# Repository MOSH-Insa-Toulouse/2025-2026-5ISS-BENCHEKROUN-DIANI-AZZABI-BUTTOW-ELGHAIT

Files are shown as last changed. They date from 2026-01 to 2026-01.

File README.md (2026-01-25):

# Gas Sensor - IoT Project

This project presents the complete development of an IoT gas sensor system, encompassing the entire pipeline from chemical synthesis to cloud integration. The work includes:

- **Chemical production** of WO₃ (tungsten trioxide) nanoparticle-based gas sensors in the laboratory
- **Electrical characterization** and datasheet development
- **LoRaWAN communication** testing with Arduino microcontroller
- **Node-RED integration** for real-time data visualization and monitoring
- **PCB system design** for the complete electronic circuit
- **Mobile application** development for user interaction

This multidisciplinary approach demonstrates a complete IoT solution from sensor fabrication to end-user interface.

## MOx Sensor Manufacturing

During a week at the AIME laboratory of INSA Toulouse, we fabricated our own MOx (Metal Oxide) gas sensor. This chapter describes how the MOx gas sensor was fabricated, from the micro-structure on the chip to the final packaged component ready for tests. The main goal is to build a sensor with interdigitated electrodes and a metal-oxide active layer (WO₃), and to make sure it can be electrically connected and handled safely during measurements.

### 1.1 MOx Sensor Architecture

The sensor is based on a small chip that includes a heating element (to control the operating temperature) and metal electrodes where the metal-oxide material will be deposited. The device is designed so that the gas-sensitive layer can change its resistance depending on the surrounding atmosphere.

### 1.2 Photolithography

First, the polysilicon heating element (used to heat the MOx resistor, lower its resistance, and remove water residues) was already manufactured in the AIME clean room by professionals. It was obtained by depositing a polysilicon layer and then patterning it using a photoresist mask activated by UV light.

Then, metallization was performed by depositing a thin aluminum layer (about 500 nm) to create electrodes and electrical contacts. After that, metal etching defined the final electrode patterns by removing unwanted aluminum. This step used a resist coating, UV exposure with a mask, development, annealing cycles, and a chemical etching bath, with microscope inspections to verify quality after each stage.

### 1.3 Metal Oxide (MOx) Synthesis

The active sensing material is tungsten trioxide (WO₃). The synthesis process consists of two steps: first, seed preparation (chemical mixing and centrifugation to collect the precipitate), and second, nanowire growth using a hydrothermal process at high temperature, followed by rinsing and storage. This method aims to produce homogeneous nanostructures suitable for gas sensing.

To place the WO₃ nanoparticles onto the interdigitated electrodes, dielectrophoresis is used: a small drop of nanoparticle solution is deposited on the chip, and an AC voltage is applied to align the particles between the electrodes. After rinsing and drying, the chip is checked under an optical microscope to confirm a uniform and well-aligned active layer.

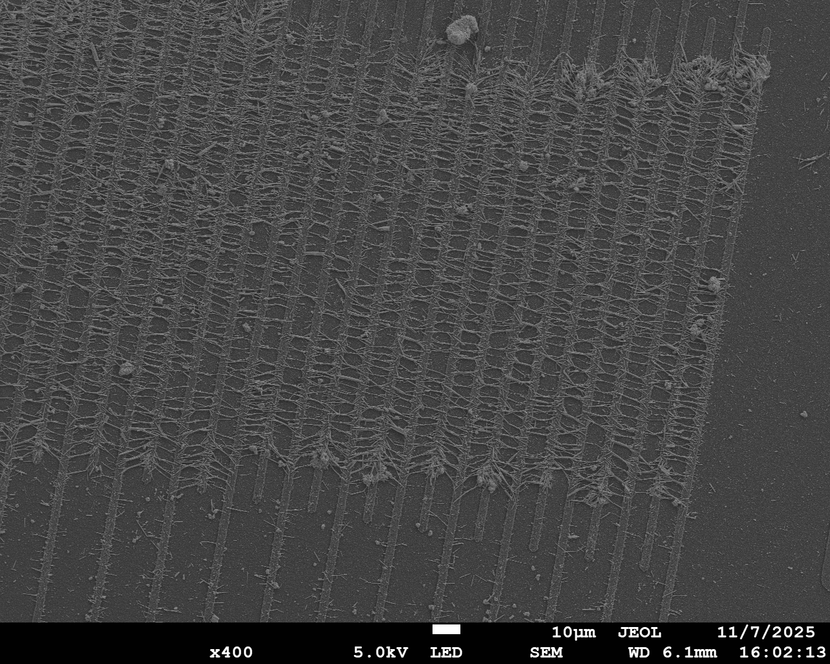
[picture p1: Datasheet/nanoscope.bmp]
Nanoscope view of the sensor


### 1.4 Packaging

Finally, the sensor is packaged using a JEDEC TO-5 metal can package with 10 pins. The chip is placed on a glass support to provide electrical isolation, and wire bonding is used to connect the chip pads to the package pins. This creates a robust component that can be connected to external electronics for characterization and integration.

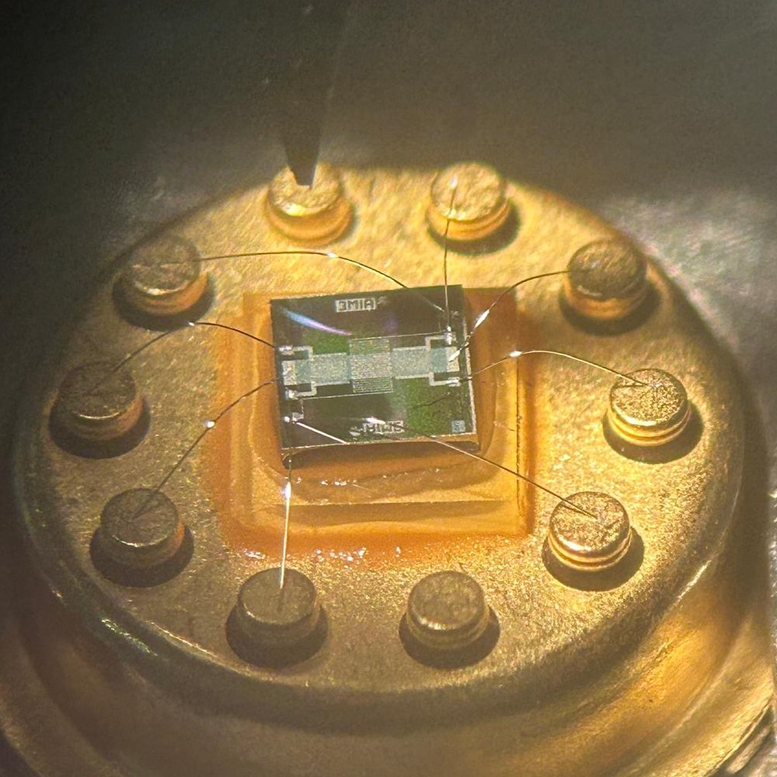
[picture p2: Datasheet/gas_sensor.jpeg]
Packaged gas sensor


## Sensor Characterization

After fabricating the sensor, we characterized two key parts of the device: the integrated thermistor (used to estimate temperature) and the MOx gas-sensing resistance (WO₃). The goal is to obtain practical electrical values that can later be used for conditioning, calibration, and integration into electronics.

### 2.1 Thermistor

The thermistor (called R_alu) is treated as a PTC component, meaning its resistance increases with temperature. Since it was not fully characterized, we assumed an approximate coefficient of 1 Ω per °C, based on a similarity with a Pt100-like behavior. A proper method would be to heat it while comparing with a reference thermometer, but this was not done, and the approximation was considered "good enough" for operating the MOx sensor.

To find the room-temperature reference resistance, we measured an I-V curve using a waveform generator and an instrumentation setup, then applied Ohm's law. The nominal resistance obtained was about 86 Ω at ambient temperature (around 21°C). We also observed non-linearity at higher voltage, likely caused by self-heating of the thermistor.

### 2.2 MOx Resistance

**Nominal resistance:** The WO₃ sensing layer has a very high resistance in its reduced form, in the GΩ range, which makes measurement difficult due to the need for a precise current source and because thermal noise becomes significant. As a result, the reported value is a rough estimate, but we obtained a typical resistance around 16 GΩ.

**Sensitivity to ethanol:** We performed an experiment to evaluate the sensor response to ethanol vapor. First, the sensor temperature is increased (around 550 K) to evaporate moisture and reduce resistance. Then the test is performed in two phases: a regeneration phase under dry air (to "regenerate" the sensor surface), followed by a detection phase under an ethanol/air mixture (about 1000 ppm). During exposure, the resistance drops with an exponential-like behavior.

From this test, we extracted several performance indicators, including:
- **Relative resistance change:** approximately 64% for our test conditions
- **Sensitivity coefficient:** based on (R_air - R_eth)/R_air
- **Response time:** about 88 seconds to reach 10% of the final value
- **Sensitivity:** 85,000 Ω/ppm
- **Detection limit:** approximately 38.3 ppm, based on the Arduino ADC resolution (10-bit), amplifier gain, and the measured sensitivity

## Integration into a Smart Device

This chapter focuses on how we integrated the MOx gas sensor into a smart embedded device using an Arduino as the main controller. The objective was to build a system able to read the sensor through an adapted analog front-end, and to prepare the hardware for a future connected version.

### 3.1 Arduino-based Prototype (Hardware Concept)

Because the final PCB/shield could not be manufactured in time, we used a prototype setup where an Arduino would interface with the gas sensor through signal conditioning. We temporarily relied on a commercial Grove gas sensor to keep the integration moving while the custom MOx board was still under development.

The system was implemented using Arduino Uno with the following sensors:
- **Temperature and humidity sensor** - for environmental monitoring
- **Grove gas sensor** - commercial reference sensor
- **Our MOx gas sensor** - sensor fabricated with WO₃ nanoparticles

### 3.2 Signal Conditioning for the MOx Sensor

Since the WO₃ sensing element can reach very high resistance (GΩ range), the sensor cannot be connected directly to the Arduino ADC. For this reason, we designed a dedicated conditioning stage (based on a transimpedance/very high gain approach) that converts the sensor behavior into a measurable voltage range for the Arduino. We validated this front-end using LTSpice simulations, and we highlight the main challenge: at such high impedance, noise becomes significant, which can limit measurement quality.

### 3.3 Filters and Noise Considerations

To improve stability, we included RC filtering at different points (input/output/feedback and power supply). The theoretical and simulated cut-off frequencies were designed to reduce low-frequency drift and attenuate noise sources such as mains-related interference (50 Hz) and EMC disturbances.

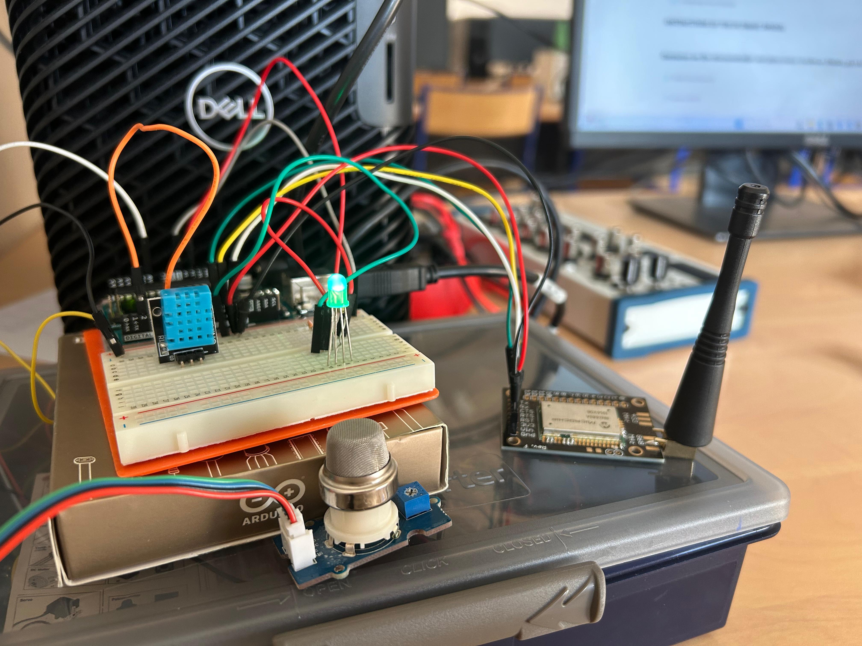
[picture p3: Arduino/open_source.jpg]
Arduino prototype with sensors


### 3.4 Arduino Code Implementation

The Arduino code (`OpenSource_V2.4.ino`) performs:
- Gas sensor reading on pin A0
- LoRaWAN communication through The Things Network (TTN)
- OLED display for local data visualization
- LED alert system when gas values exceed the threshold

**Main code features:**
- Analog reading of the gas sensor (A0)
- Alert threshold: GAZ_VALUE > 100
- Data transmission via LoRaWAN every 10 seconds
- OLED display for visual feedback
- LED alert for gas detection

## Node-RED

The Node-RED system was implemented to receive and process sensor data through the MQTT protocol, connecting to ChirpStack/The Things Network. This provides a visual programming interface for data flow management and real-time monitoring of the gas sensor system.

### 4.1 System Architecture

The Node-RED implementation creates a complete IoT data pipeline that:
- Subscribes to MQTT topics from the LoRaWAN network server (ChirpStack/TTN)
- Processes incoming sensor data in real-time
- Provides visual dashboards for monitoring
- Implements alert logic based on sensor thresholds
- Stores historical data for analysis

### 4.2 MQTT Integration

The system uses an MQTT input node configured to subscribe to the application-specific topic:
- **Topic pattern**: `application/[app-id]/device/+/event/up`
- **QoS Level**: 2 (exactly once delivery)
- **Protocol**: MQTT over ChirpStack/The Things Network

This ensures reliable reception of all uplink messages from the deployed gas sensors in the field.

### 4.3 Data Processing Flow

The implemented flow performs several processing stages:

1. **Message Filtering**: Filters only uplink events (`/event/up`) to ignore other event types
2. **Base64 Decoding**: Extracts and decodes the base64-encoded payload from the LoRaWAN message
3. **Payload Parsing**: Interprets the binary data structure:
   - Byte 0: Sensor ID (identifies which sensor sent the data)
   - Bytes 1-2: 16-bit big-endian integer containing the raw sensor value
   - Conversion: Divides raw value by 100 to obtain the actual measurement
4. **Alert Logic**: Implements threshold-based alerting:
   - Normal operation: value ≤ 80
   - Alert state: value > 80 (triggers "Help" notification)
5. **Data Distribution**: Routes processed data to multiple outputs (debug console, dashboard widgets, data storage)

### 4.4 Node-RED Flow

The visual flow includes:
- MQTT subscriber node for data ingestion
- Function nodes for data transformation and business logic
- Debug nodes for development and troubleshooting
- Dashboard UI nodes for real-time visualization
- Chart nodes for historical trend display

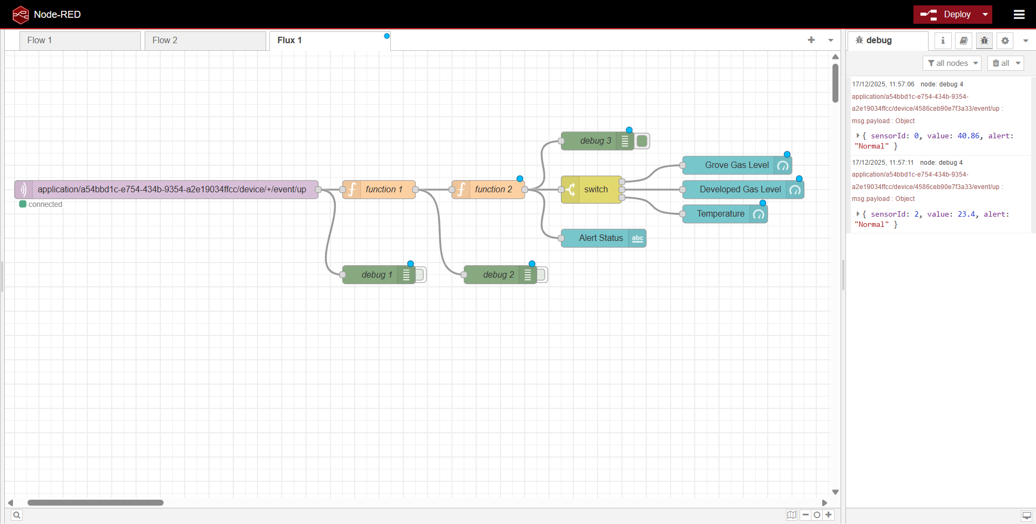
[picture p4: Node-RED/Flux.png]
Node-RED Flow


### 4.5 Dashboard

The Node-RED dashboard provides a web-based interface for real-time monitoring with:

**Display Elements:**
- **Current sensor value**: Real-time display of gas concentration readings
- **Alert status**: Visual indicator showing "Normal" or "Help" states
- **Historical chart**: Time-series graph showing sensor readings over time
- **Sensor identification**: Displays which sensor (by ID) is reporting

**Features:**
- Responsive web interface accessible from any device
- Automatic updates as new data arrives
- Color-coded alerts for quick status assessment
- Historical data visualization for trend analysis

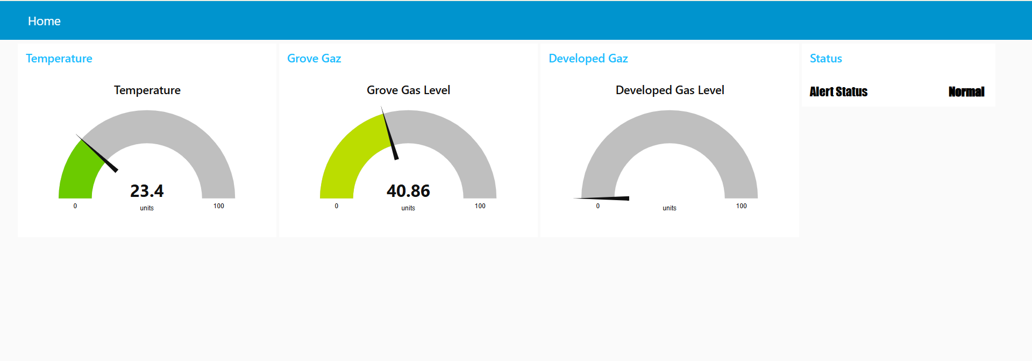
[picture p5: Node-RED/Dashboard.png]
Node-RED Dashboard


### 4.6 Implementation Details

The complete flow configuration is available in the `flows.json` file, which can be imported directly into Node-RED for deployment. The implementation uses standard Node-RED nodes along with the dashboard palette for UI components, making it easy to customize and extend for additional features or sensors.

## The electrical circuit
Here is the complete electrical diagram of our system. It consists of a gas-type switch, a variable resistor using an MCP41100 digital potentiometer, another variable resistor using an MCP41100 digital potentiometer, an Arduino Uno, a gas sensor, and a LoRa module.

Capture d’écran 2026-01-21 à 14 50 42

The fabricated gas sensor exhibits a very high resistance that varies depending on the type and presence of gas. Its resistance is on the order of gigohms, resulting in an extremely low current of the order of nanoamperes flowing into the ADC. Since an Arduino uses a 10-bit ADC, the sensor output signal must be amplified. To address this, we designed an amplification circuit based on an operational amplifier and validated it through LTSpice simulations.
Below is the LTSpice circuit:

Capture d’écran 2026-01-21 à 14 50 59

The circuit includes three filters with different cutoff frequencies to reduce noise and shape the signal:
- A low-frequency filter to suppress sensor noise,
- A notch filter to attenuate 50 Hz power-line interference,
- An anti-aliasing filter to prevent distortion during ADC sampling.

Transient simulations confirmed correct amplifier operation, with a gain of 101, matching theoretical calculations. Frequency analysis using Bode diagrams showed an overall gain of 140 dB, consistent with the expected transfer function. FFT analysis further demonstrated effective noise reduction, particularly at 50 Hz, while highlighting the trade-off between noise suppression and signal distortion when filter capacitance is increased excessively.
Overall, the simulations validate the amplifier design and confirm its suitability for accurately measuring low-current gas sensor signals using low-cost data acquisition systems.

## PCB Design
To bring all the components of our sensor system together, we designed a dedicated Printed Circuit Board (PCB). This board combines all stages of the system into a unified and compact design, providing an optimized layout, enhanced reliability, and efficient operation. The detailed PCB design is shown in the figure below.

Capture d’écran 2026-01-25 à 10 23 23

Below, there is a 3D view of the PCB after conception.

- Front view:

Capture d’écran 2026-01-25 à 10 24 11

- Back view:

Capture d’écran 2026-01-21 à 14 51 32

## MIT App Inventor

The MIT App Inventor application is designed to interface with the Arduino, allowing users to control the system and monitor sensor data in real time.

  Capture d’écran 2026-01-21 à 14 52 11

This MIT App Inventor application functions as a Bluetooth remote control for an Arduino system. It allows the user to first connect to a Bluetooth module (such as HC-05) through a list of available devices, and then send commands either by pressing buttons or using voice commands. The "LED ON" button sends the number 1 to turn on the LED, the "LED OFF" button sends 2 to turn it off, and if the voice recognition detects the word "blink," the app sends 3 to make the LED blink. At the same time, the application can receive and display messages sent by the Arduino via Bluetooth.

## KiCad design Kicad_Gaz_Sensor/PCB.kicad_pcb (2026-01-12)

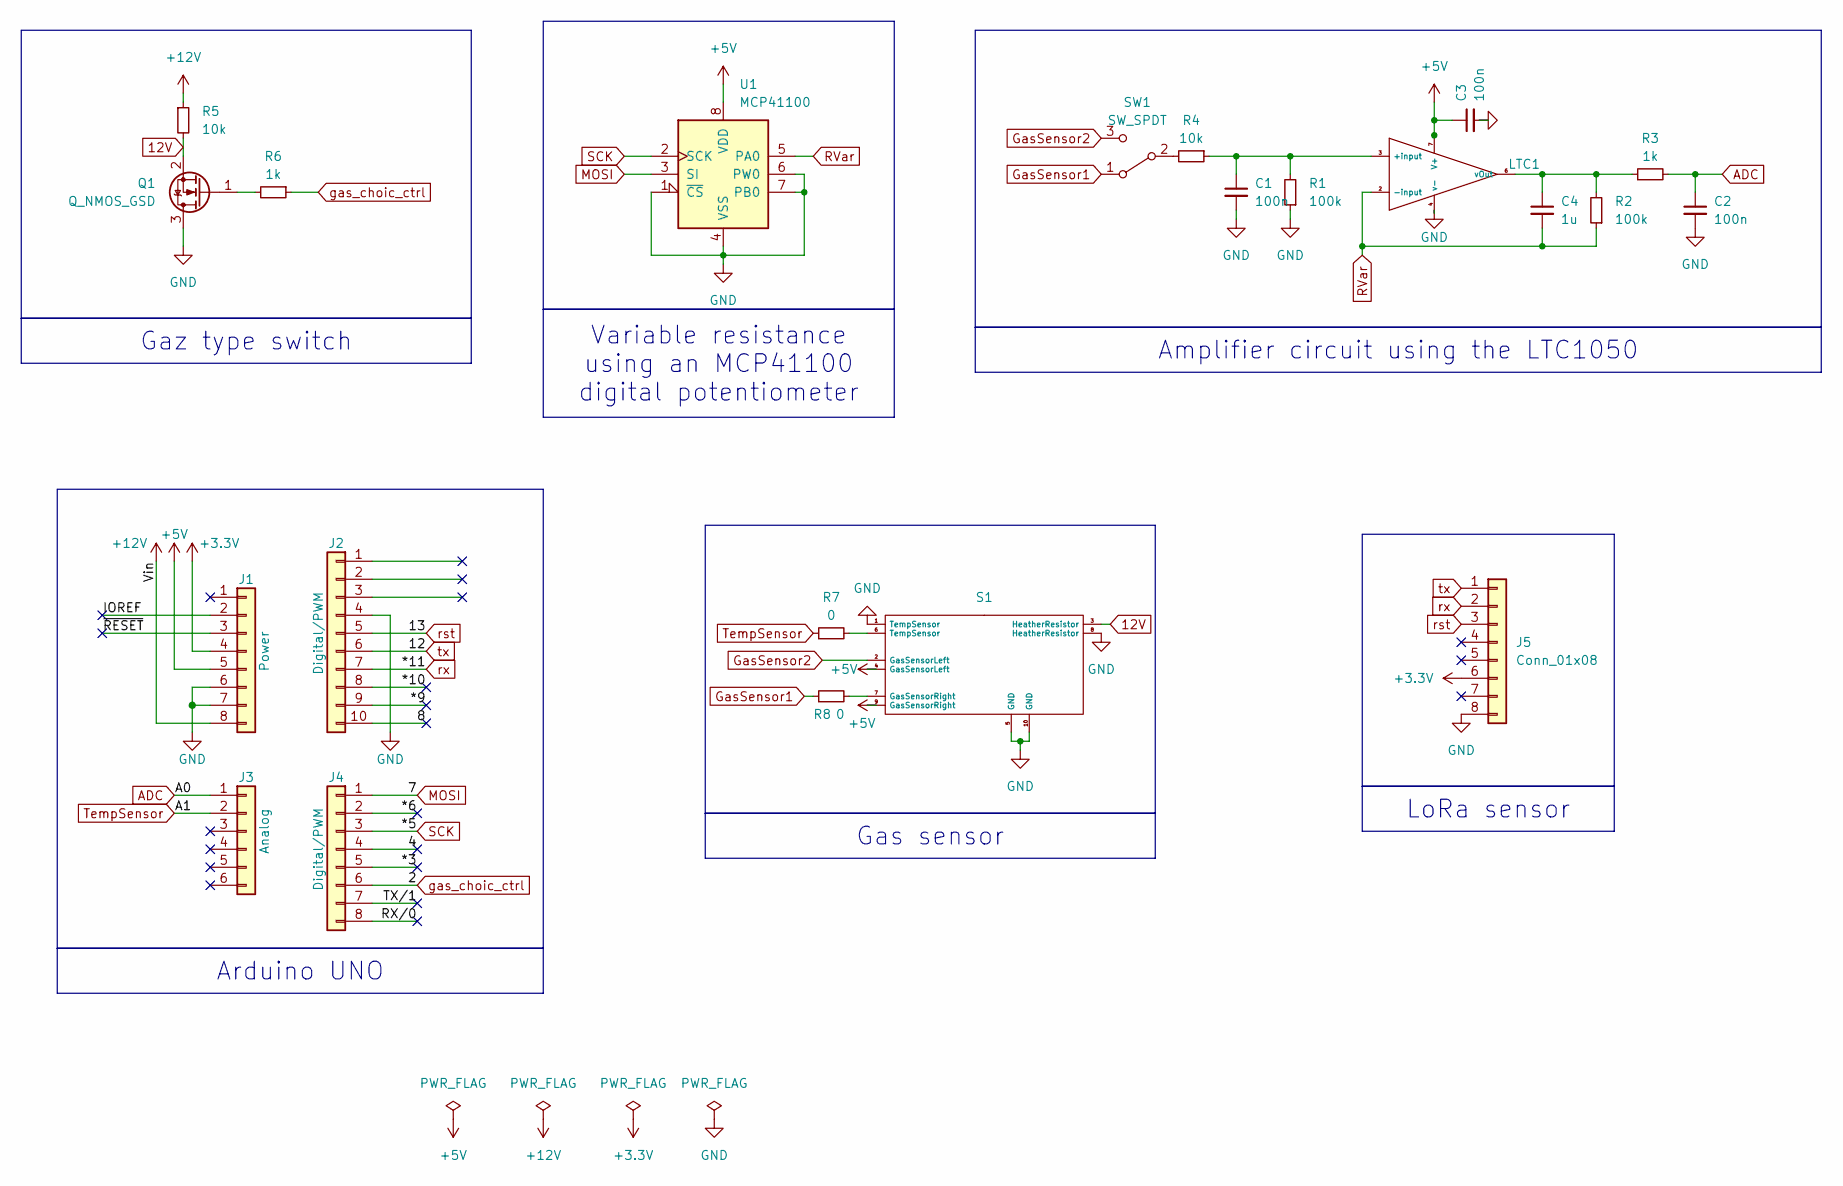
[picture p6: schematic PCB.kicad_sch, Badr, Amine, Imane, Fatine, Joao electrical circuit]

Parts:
C1, C2, C3: 100n; C_Disc_D3.0mm_W1.6mm_P2.50mm
C4: 1u; C_Disc_D3.0mm_W1.6mm_P2.50mm
J1: Power; PinSocket_1x08_P2.54mm_Vertical
J2: Digital/PWM; PinSocket_1x10_P2.54mm_Vertical
J3: Analog; PinSocket_1x06_P2.54mm_Vertical
J4: Digital/PWM; PinSocket_1x08_P2.54mm_Vertical
J5: Conn_01x08; PinSocket_1x08_P2.54mm_Vertical
LTC1: DIP-8_W7.62mm_LongPads
Q1: Q_NMOS_GSD; TO-220-3_Vertical
R1, R2: 100k; R_Axial_DIN0204_L3.6mm_D1.6mm_P5.08mm_Horizontal
R3, R6: 1k; R_Axial_DIN0204_L3.6mm_D1.6mm_P5.08mm_Horizontal
R4, R5: 10k; R_Axial_DIN0204_L3.6mm_D1.6mm_P5.08mm_Horizontal
R7, R8: 0; R_Axial_DIN0204_L3.6mm_D1.6mm_P5.08mm_Horizontal
S1: TO-5-10_Window
SW1: SW_SPDT; SW_Push_2P2T_Toggle_CK_PVA2xxH2xxxxxxV2
U1: MCP41100; DIP-8_W7.62mm

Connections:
12V: Q1.2 (S), R5.2, S1.3 (HeatherResistor)
+3.3V: J1.4, J5.6
+5V: C3.1, J1.5, LTC1.7 (V+), S1.4 (GasSensorLeft), S1.9 (GasSensorRight), U1.8 (VDD)
+12V: J1.8, R5.1
/4: J4.4
/8: J2.10
/*3: J4.5
/*6: J4.2
/*9: J2.9
/*10: J2.8
/IOREF: J1.2
/RX/0: J4.8
/TX/1: J4.7
/~RESET: J1.3
ADC: C2.1, J3.1, R3.2
GND: C1.2, C2.2, C3.2, J1.6, J1.7, J2.4, J5.8, LTC1.4 (v-), Q1.3 (D), R1.1, S1.1 (TempSensor), S1.5 (GND), S1.8 (HeatherResistor), S1.10 (GND), U1.1 (~CS), U1.4 (VSS), U1.6 (PW0), U1.7 (PB0)
GasSensor1: R8.1, SW1.1 (A)
GasSensor2: S1.2 (GasSensorLeft), SW1.3 (C)
MOSI: J4.1, U1.3 (SI)
unnamed: C1.1, LTC1.3 (+input), R1.2, R4.1
unnamed: C4.1, LTC1.6 (vOut), R2.2, R3.1
unnamed: Q1.1 (G), R6.2
unnamed: R7.2, S1.6 (TempSensor)
unnamed: R8.2, S1.7 (GasSensorRight)
unnamed: R4.2, SW1.2 (B)
RVar: C4.2, LTC1.2 (-input), R2.1, U1.5 (PA0)
SCK: J4.3, U1.2 (SCK)
TempSensor: J3.2, R7.1
gas_choic_ctrl: J4.6, R6.1
rst: J2.5, J5.3
rx: J2.7, J5.2
tx: J2.6, J5.1

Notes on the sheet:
Gas sensor
Amplifier circuit using the LTC1050
LoRa sensor
Variable resistance using an MCP41100 digital potentiometer
Arduino UNO
Gaz type switch

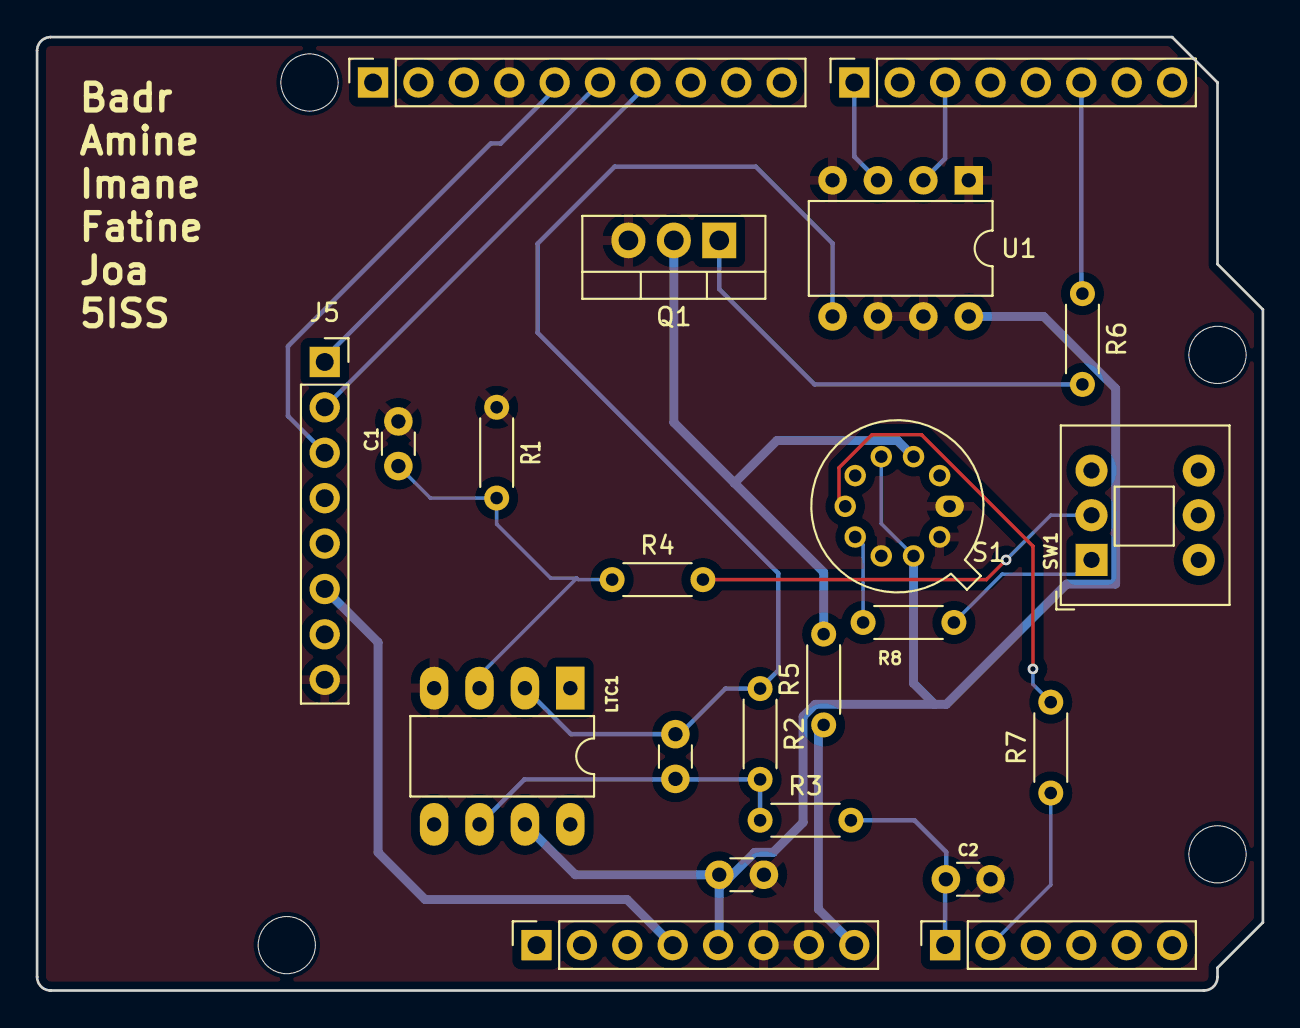
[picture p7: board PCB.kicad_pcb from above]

Board: 2 copper layers, 68.6 x 53.3 mm, 26 parts (0 on the bottom side), 22 nets.

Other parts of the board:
MH1, MH2, MH3, MH4: MountingHole_3.2mm

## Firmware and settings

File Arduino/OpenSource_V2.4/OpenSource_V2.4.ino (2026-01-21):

#include <TheThingsNetwork.h>
#include <TheThingsMessage.h>
#include <SoftwareSerial.h>

// Set AppEUI and AppKey
const char *appEui = "9314122f9f48664f";
const char *appKey = "77F85835964FC8C511F87CE864B96A6D";

#include "SSD1306Ascii.h"
#include "SSD1306AsciiAvrI2c.h"
#define I2C_ADDRESS 0x3C
SSD1306AsciiAvrI2c oled;

SoftwareSerial loraSerial(10, 11); //TX, RX

#define debugSerial Serial
#define freqPlan TTN_FP_EU868

#define GAZ_SENSOR_PIN A0
#define LED_PIN 4

TheThingsNetwork ttn(loraSerial, debugSerial, freqPlan);

void setup()
{
  loraSerial.begin(57600);
  debugSerial.begin(57600);

  // Wait a maximum of 10s for Serial Monitor
  while (!debugSerial && millis() < 10000)
    ;

  debugSerial.println("-- STATUS");
  ttn.showStatus();

  debugSerial.println("-- JOIN");
  ttn.join(appEui, appKey);

  pinMode(LED_PIN, OUTPUT);

  oled.begin(&Adafruit128x64, I2C_ADDRESS);
  oled.setFont(Adafruit5x7);  
  oled.clear();
  oled.set2X();
  oled.println("Hello user1");

}

void loop()
{
  debugSerial.println("-- LOOP");

  byte GAZ_VALUE = analogRead(GAZ_SENSOR_PIN);
  debugSerial.print("GAZ_VALUE : ");
  debugSerial.println(GAZ_VALUE);
  if (GAZ_VALUE >100){
    digitalWrite(LED_PIN,HIGH);
    oled.clearField(0,2,5);
    oled.println("HELP");
  }else {
    digitalWrite(LED_PIN,LOW);
    oled.clearField(0,2,5);
  }

  ttn.sendBytes(&GAZ_VALUE, 1);

  delay(10000);
}

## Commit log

2026-01-12 Create Arduino_code
2026-01-12 Create README with system overview and details
    Added detailed documentation on the electrical circuit, PCB design, and MIT App Inventor application for the sensor system.
2026-01-21 Update README with new images and app details
    Updated images in the README to reflect recent changes and improvements in the electrical circuit and PCB design sections. Added details about the MIT App Inventor application functionalities.
2026-01-21 Add Arduino code, Node-RED flows, and assets
    Initial commit with Arduino sensor code, Node-RED flow configuration, dashboard images, and gas sensor datasheet. Enables LoRaWAN sensor data transmission and visualization via Node-RED dashboard.
2026-01-21 Complete README with nanoparticle manufacturing, Arduino, and Node-RED sections
2026-01-21 Update MOx sensor manufacturing section with detailed fabrication process
2026-01-21 Add sensor characterization section with thermistor and MOx resistance analysis
2026-01-21 Add image assets for Arduino and datasheets
    Added open_source.jpg to the Arduino directory and gas_sensor.jpeg and nanoscope.bmp to the Datasheet directory. These images may be used for documentation or reference purposes.
2026-01-21 Add Arduino integration chapter with signal conditioning and noise filtering details
2026-01-21 Expand Node-RED section with detailed architecture, MQTT integration, and data processing flow
2026-01-25 Replace PCB images with updated versions
    Updated images in the PCB Design section with new captures.
2026-01-25 Modify PCB image size in README.md
    Updated PCB design image dimensions in README.
2026-01-25 Replace PCB images with updated versions
    Updated PCB design images with higher resolution and dimensions.
